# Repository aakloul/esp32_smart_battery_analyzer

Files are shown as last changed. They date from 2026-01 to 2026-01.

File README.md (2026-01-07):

## esp32_smart_battery_analyzer

This device is designed for testing Lithium Battery. It is powered by ESP32 chip that controls four mode of operation: 

1. Charge Mode, 
2. Discharge Mode, 
3. Analyze Mode, 
4. IR Test Mode

This repository is fully featured with schematics (gerber files), bill of materials, stl for 3-D printing, source code for live UI, plotting and retention of battery profiles.

The source code can manage a fleet of those devices analyzing batteries in parallel

### Bluetooth fleet of Smart‑Charger and Battery‑Profile Analyzer

A lightweight, asyncio‑driven Python application that:

- Scans BLE (Eddystone‑TLM) advertisements from ESP32‑based Smart‑Chargers.
- Stores telemetry in a local SQLite database.
- Shows live, curses‑based tables on the terminal.
- Provides a set of scripts to plot historic charge/discharge curves.
- The project follows a tiny MVC pattern (Model ↔ View ↔ Controller) and is deliberately kept dependency‑free apart from Bleak (the BLE stack).

### 🎯 Features at a glance

| Feature	| Description |
| -	| - |
| **BLE scanner** | asynchronous, runs on any Linux host (Pi, laptop, VM).	|
| **Curses UI** | pure‑ASCII, works on head‑less devices.	|
| **SQLite persistence** | simple DAO layer, easy to export data.	|
| **Live plotting** | Matplotlib scripts for single‑ or multi‑battery views.	|
| **Modular architecture** | scanner, repository, UI, and utilities are isolated.	|
| **Extensible** | add new telemetry fields or UI panels with minimum touching of the DB layer.	|

### 📂 Repository layout

```
esp32_smart_battery_analyzer/
│
├─ datasheet_schematics/   # PDFs of schematics & datasheets
├─ gerber/                 # Gerber files for PCB production
├─ stl/                    # 3D‑printable housing & button models
├─ bom/                    # Bill‑of‑Materials (components, parts number)
└─ sources/                # Python source code
   │
   ├─ main.py                  # Bootstrap / async event‑loop starter
   ├─ app_logger.py            # Centralised logging helper
   ├─ controller.py            # MVC controller (model ↔ view glue)
   ├─ curses_view.py           # Curses‑based UI implementation
   ├─ eddystone_scanner.py     # BLE scanner → controller callback
   ├─ hex_helper.py            # HMAC, hex utilities & byte helpers
   ├─ models.py                # Dataclasses: Device, Battery, Telemetry
   ├─ telemetry_db.py          # Low‑level SQLite wrapper (DAO)
   ├─ telemetry_repository.py  # Repository façade (business‑logic service)
   ├─ archive_sqlite.py        # Merge many DBs into a master.db
   ├─ timing_decorator.py      # Simple profiling decorator
   │
   ├─ telemetry_live_plot.py   # Plot a single battery profile live
   ├─ multi_live_plot.py       # Plot several profiles side‑by‑side live
   ├─ overlay_battery_plot.py  # Overlay multiple profiles on one chart
   ├─ ... (other helper scripts)
   └─ Smart_Multipurpose_Battery_Tester
       │
       └─ Smart_Multipurpose_Battery_Tester.ino     # ESP32 sketch (e.g arduino)
```

## 🚀 Getting started

### Prerequisites

- Python ≥ 3.8
- pip (pyenv or a virtual‑env manager of your choice is recommended)
- A Linux host with BLE support (Raspberry Pi, Ubuntu, Debian, …)

### Installation

```bash
# 1️⃣ Clone the repo
git clone https://github.com/aakloul/esp32_smart_battery_analyzer.git
cd esp32_smart_battery_analyzer

# 2️⃣ (Optional) create a virtual environment
python -m venv .venv
source .venv/bin/activate   # on Windows: .venv\Scripts\activate

# 3️⃣ Install dependencies
pip install -r requirements.txt

# 4️⃣ Run the application
python sources/main.py
```

### Plotting utilities

```python
# Plot a set of historic profiles (master.db must exist)
python sources/overlay_battery_plot.py --db ~/battery_profiles/master.db --batteries 2 3 4 5 6

# Live plot of a single battery while the charger runs
python sources/telemetry_live_plot.py

# Compare several batteries side‑by‑side in real time
python sources/multi_live_plot.py``
```

### 🏗️ Architecture Overview

#### Layered responsibilities

| Layer	| Responsibility	| Example class |
| - | - | - |
| Presentation / Runtime |	Starts the async loop, hands callbacks to Bleak	| main.py |
| Domain / Business Logic |	Decodes BLE packets, decides what to store	| EddystoneScanner |
| Application Service	| Coordinates persistence, hides DB details	| TelemetryRepository |
| Infrastructure / Persistence |	Raw SQLite commands, schema creation	| TelemetryDB |
| Utility	| Hex formatting & HMAC verification	| HexHelper |

#### Mermaid class diagram

```mermaid
classDiagram
    %% Core data structures
    class Device {
        +str mac
        +str name
    }
    class Battery {
        +float capacity_mAh
        +float voltage_V
    }
    class Telemetry {
        +datetime timestamp
        +float voltage
        +float current
        +float temperature
    }

    %% Repositories / DAOs
    class TelemetryDB {
        +connect()
        +execute(sql, params)
        +close()
    }
    class TelemetryRepository {
        +save_telemetry(Telemetry)
        +get_by_device(mac)
    }

    %% Scanner & Controller
    class EddystoneScanner {
        +start_scan(callback)
        +stop_scan()
    }
    class Controller {
        +on_packet(packet)
        +update_model()
    }

    %% UI
    class CursesView {
        +draw_header()
        +draw_row(Device)
        +refresh()
    }

    %% Utilities
    class HexHelper {
        +bytes_to_hex(bytes)
        +calc_hmac(key, data)
    }

    %% Relationships
    Device "1" <-- "0..*" Battery : records
    Battery "1" <-- "0..*" Telemetry : records
    TelemetryRepository --> TelemetryDB : uses
    TelemetryDB --> Telemetry : uses
    Controller --> TelemetryRepository : persists
    Controller --> CursesView : updates UI
    CursesView --> Controller : user actions
    EddystoneScanner --> Controller : callback
    EddystoneScanner  ..> HexHelper : validates HMAC
```
The diagram shows the main data classes (Device, Battery, Telemetry) and how the scanner, controller, repository, DB wrapper and UI interact.

#### Principles

The codebase **testable, maintainable, and future‑proof with clear separation**: 
- The scanner never touches SQL; 
- the repository never knows about BLE.
- The UI lives in its own module and the whole application follows a very lightweight MVC pattern (Model = dataclasses + SQLite, View = curses based terminal table, Controller = glue that updates the model and tells the view to redraw).

**Lightweight**: All modules import only the Python standard library plus bleak (already required for BLE). No extra third‑party UI frameworks are needed, keeping the package lightweight and easy to install.

**Requires minimum hardware specifications**, all the UI is ASCII based to allow the capture to run on a headless device (e.g raspberry pi)

**Responsiveness** of the UI and scanning with asyncio and threading

## 🛠️ Development & Contribution

1. Code style – run black . and flake8 before committing.

2. Testing – add unit tests under a tests/ directory (pytest recommended).

3. Profiling UI loops – use the built‑in cProfile wrapper:

```python -m cProfile -o profile.pstats main.py```

After you quit the program, inspect the hot spots:

```python
python - <<'PY'
import pstats, sys
p = pstats.Stats('profile.pstats')
p.strip_dirs().sort_stats('cumtime').print_stats(20)
PY
```
Look for functions that consume a lot of cumulative time (_draw_table, _draw_log, parse_advertisement, etc.). Those are the places to optimise.

4. Pull requests – fork the repo, push your branch, and open a PR. Include a short description of the change and reference any related issue.

## References: 

| Link | |
| - | - |
| [Instructables](https://www.instructables.com/DIY-Smart-Multipurpose-Battery-Tester/) | detailed instructions and schematics |
| [Youtube](https://youtu.be/QN8AuUfg2y8?si=btL3awTXZG-g8NH7) | |
| [PCBWay](https://www.pcbway.com/project/shareproject/DIY_Smart_Multipurpose_Battery_Tester_aaf0922e.html) | PCB production |
| [Seed Studio](https://wiki.seeedstudio.com/XIAO_ESP32C3_Getting_Started/) | Getting Started with ESP32-C3 |
| [Nimble on ESP32-C](https://wiki.seeedstudio.com/XIAO_ESP32C3_Bluetooth_Usage/) | Bluetooth with ESP32-C3 |
| [Nimble-Arduino](https://github.com/h2zero/NimBLE-Arduino/blob/master/examples/BLE_EddystoneTLM_Beacon/BLE_EddystoneTLM_Beacon.ino) | Nimble Eddystone-TLM Beacons |
| [HMAC](https://www.dfrobot.com/blog-921.html?srsltid=AfmBOootriPzmv8BGEABjtGPIYKFY8ldHPTuY8WLx7NJhZGtg5EIOsAH) | HMAC implementation for esp32 chip |

## 📄 License
The code is released under the GPLv3 License – see the LICENSE file for details.

## 🙋‍♀️ Need help?

- Open an issue on GitHub.
- Join the discussion in the Discussions tab for design ideas.
- For quick questions, drop a comment on the relevant PR or issue.

Happy hacking! 🚀

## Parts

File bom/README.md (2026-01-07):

Updated BOM Note – Part Replacement

## Summary

The circuit does not need a MOSFET because the op‑amp supplies a constant low‑voltage current. Replacing the discontinued IRL540 with a simple bipolar transistor works fine – the 2SD972 has been tested successfully

## ⚠️ Important Warnings

| Issue |	Recommendation |
| - |	- |
| IRL540 discontinued	| Do not try to source it; it’s no longer manufactured. |
| PCBWay’s suggested substitute – IRFZ44NPBF	| DO NOT USE. In a low‑voltage gate‑drive configuration the IRFZ44N will not turn on properly, resulting in little or no current flow. |

## Recommended Replacement Options

| Part	|	Type	|	Why it fits	|
| -	|	-	|	- |
| 2SD972	|	NPN bipolar transistor |	Proven to work in this design; handles the required current with the op‑amp’s low‑voltage output. |
|IRLZ44N (logic‑level MOSFET)	|	MOSFET	|	Suitable when you do need a MOSFET driven directly from 3.3 V/5 V microcontrollers (e.g., Arduino, ESP32). It turns fully on at low gate voltages, unlike the standard IRFZ44N which requires ~10 V. |

- Tip: If you ever need a MOSFET for a higher‑voltage gate‑drive application, choose a true logic‑level device (e.g., IRLZ44N) rather than a standard‑level part.
- Tip: For direct use with 3.3V/5V microcontrollers (like Arduino), the IRLZ44N (logic-level) is a better, more efficient choice than the standard IRFZ44N. The primary difference is that the IRLZ44N is a logic-level MOSFET, meaning it can be fully controlled by low-voltage logic (like a 3.3V or 5V microcontroller I/O pin, e.g esp32 chip), while the IRFZ44N is a standard-level MOSFET that requires a higher gate voltage (typically 10V) for full turn-on. 

## Further Reading

Reddit discussion – a community‑curated list of additional MOSFET/ transistor alternatives (link here [Reddit post](https://www.reddit.com/r/AskElectronics/comments/q2pisu/irl_vs_irf_mosfet_can_i_use_an_irf_mosfet_for/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,thus%20standard%2Dlevel.) for more alternatives. )

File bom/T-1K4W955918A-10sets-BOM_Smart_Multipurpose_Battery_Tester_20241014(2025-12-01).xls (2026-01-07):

PCBWay Bom Quotation, Product No.:T-1K4W955918A
Item # | *Designator | *Qty | Manufacturer | *Mfg Part # | Description / Value | Vendor Part # | *Package/Footprint | Your Instructions / Notes | *Unit Price(10 sets) | *Total | *Delivery Time | *Actual Purchase Mfg Part # | *PCBWay Note | Customer Reply | PCBWay Update
1 | D1,D2 | 2 | MDD | SS34 | SS34 | LCSC『 』C8678 | DO-214AC_L4.3-W2.7-LS5.3-RD |  | $0.078 | $1.560
2 | C12,C9,C10,C11,C6,C7,C8,C3 | 8 |  | 0805B104J250CT | 100nF | LCSC『 』C396717 | C0805 |  | $0.018 | $1.440
3 | C1,C2,C4,C5 | 4 |  | CL21A106KPFNNNE | 10uF | LCSC『 』C17024 | C0805 |  | $0.021 | $0.840
4 | R18,R19,R20 | 3 |  | 0805W8F1002T5E | 4.7kΩ | LCSC『 』C17414 | R0805 |  | $0.004 | $0.120 |  | 0805W8F4701T5E
5 | U4 | 1 |  | SKU 113991054 | XIAO ESP32C3 | Seeedstudio | XIAO-ESP32C3-MODULE |  | $8.578 | $85.780 | 7-10 Workdays | 113991054
6 | BZ | 1 |  | GMD0955YB-3V2700 | 2700Hz | LCSC『 』C252933 | BUZ-TH_BD9.0-P5.00-D0.6-FD |  | $0.498 | $4.980
7 | MOD,UP, DOWN | 3 |  | Switch6*6*11 | MOD,UP, DOWN | LCSC『 』C91998 | SW-SMD_4P-L6.0-W6.0-P4.50-LS8.5 | https://item.szlcsc.com/2997628.html?fromZone=s_s__%2522TS-1095PS-A8B3-C3D2%2522 | $0.052 | $1.560 |  | TS-1095PS-A8B3-C3D2
8 | BAT | 1 |  | PH-2P卧贴 | PH2.0-2PWB | LCSC『 』C47647 | CONN-SMD_2P-P2.00_PH2.0-SPWB |  | $0.084 | $0.840
9 | BT | 1 |  | BH-18650-B1BA002 | BH-18650 | LCSC『 』C2988620 | BATTERY-SMD_18650-1S-L77.1-W20.7-1 |  | $1.563 | $15.630 |  |  | 【 Sensitive Components 】 : Before mounting, dehumidification and baking are required. Bake at 60-70 degrees for 10-25 minutes
10 | DSP | 1 |  | HS96L03W2C03 | OLED 0.96 INCH 128X64 I2C | LCSC『 』C5248080 | OLED 0.96 INCH 128X64 I2C |  | $2.341 | $23.410
11 | LED | 1 |  | 17-21SURC/S530-A3/TR8 | LED-0805_R | C72037 | LED0805_RED |  | $0.033 | $0.330
12 | Q3 | 1 |  | 2SD972 | IRL540 discontuned --> replace with iscSilicon NPN Darlington Power Transistor (https://www.alldatasheet.com/datasheet-pdf/view/895356/ISC/2SD972.html) | LCSC『 』C2586 | TO-220-3_L10.0-W4.5-P2.54-L |  | $0.250 | $2.500 |  |  |  | IRFZ44NPBF won't work because it's gate threshold is too high (around 10V) and therefore we need another TO-220 FET that can be activated around 4V
13 | R1,R2,R6 | 3 |  | RMC08051K5%N | 5.1kΩ | LCSC『 』C269727 | R0805 |  | $0.005 | $0.150 |  | 0805W8F5101T5E
14 | R3,R4,R13,R7,R9 | 5 |  | RMC08051K5%N | 1kΩ | LCSC『 』C269727 | R0805 |  | $0.005 | $0.250
15 | R5 | 1 |  | RMC08051K5%N | 10kΩ | LCSC『 』C269727 | R0805 |  | $0.007 | $0.070 |  | 0805W8F1002T5E
16 | R11 | 1 |  | PTFR0805B33K0N9 | 33kΩ | LCSC『 』C351577 | R0805 |  | $0.561 | $5.610
17 | R12,R14 | 2 |  | 0805W8F1002T5E | 10kΩ | LCSC『 』C17414 | R0805 |  | $0.005 | $0.100
18 | R16 | 1 |  | RC0805JR-07200KL | 200K | LCSC『 』C114235 | R0805 |  | $0.007 | $0.070
19 | R17 | 1 |  | RMC0805100K5%N | 100kΩ | LCSC『 』C269722 | R0805 |  | $0.016 | $0.160
20 | R8 | 1 |  | RS-05K2001FT | 2k | LCSC『 』C132365 | R0805 |  | $0.008 | $0.080
21 | R15 | 1 |  | 25121WF100LT4E | 100mΩ/1W | LCSC『 』C25466 | R2512 |  | $0.142 | $1.420
22 | USB_5V | 1 |  | TYPE-C 6P | TYPE-C 6P | LCSC『 』C456012 | TYPE-C-SMD_TYPE-C-6P |  | $0.049 | $0.490
23 | HS | 1 |  | 23.5*16*25 | 23.5*16*25 | LCSC『 』C4661 | HEATSINK-TH_L23.5-W16.0-P18.0_XSD2156-067 | 若原型号型号，可以购买https://item.taobao.com/item.htm?id=787746231050&spm=a21m98.27004841『 』用右边这个链接『 』https://item.taobao.com/item.htm?id=904397829229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 | $0.223 | $2.230 |  | Two nail heat sinks of 23.5*16*25
24 | Q1 | 1 |  | AO3401A | AO3401A | LCSC『 』C5122001 | SOT-23-3_L2.9-W1.3-P1.90-LS2.4-BR |  | $0.087 | $0.870
25 | Q2 | 1 |  | 2SC2411KT146R | 2SC2411 | LCSC『 』C122622 | SOT-346_L2.9-W1.6-P1.90-LS2.8-TR-CW |  | $0.073 | $0.730
26 | U1 | 1 |  | LP4060B5F | LP4060 | LCSC『 』C517259 | TSOT-23-5_L2.9-W1.6-P0.95-LS2.8-BR |  | $0.073 | $0.730
27 | U2 | 1 |  | AP6685 | AP6685 | LCSC『 』C2849566 | SOT-23-5_L2.9-W1.6-P0.95-LS2.8-BL |  | $0.103 | $1.030
28 | U3 | 1 | HXY MOSFET(华轩阳电子) | XC6206P332MR | XC6206P332MR | LCSC『 』C5148692 | SOT-23-3_L2.9-W1.3-P1.90-LS2.4-BR |  | $0.099 | $0.990
29 | U5 | 1 |  | LMV321B-TR | LMV321B-TR | LCSC『 』C248567 | SOT-23-5_L3.0-W1.7-P0.95-LS2.8-BR |  | $0.204 | $2.040
30 | U6 | 1 |  | LM385-1.2 | LM385-1.2 | LCSC『 』C5274784 | SOT-23-3_L2.9-W1.4-P1.90-LS2.5-BR |  | $0.388 | $3.880
31 | PWR | 1 |  | SK-12E12-G050 | SK-12E12-G050 | LCSC『 』C2848870 | SW-TH_G-SWITCH_SK-12E12-G050 |  | $0.118 | $1.180
32 | / | 1 | XFCN | PZ254V-11-04P | 1x4 male header, used for DSP |  |  |  | $0.044 | $0.440
33 | / | 1 |  |  | Insulation sheet and insulation cap for HS |  |  | https://item.taobao.com/item.htm?abbucket=2&id=621632934312&ns=1&spm=a21n57.1.0.0.13a2523cTEn6rm | $0.150 | $1.500 |  | Insulating sheet + insulating cap
34 | / | 1 |  |  | M3 screw for HS |  |  | https://item.taobao.com/item.htm?abbucket=2&id=621632934312&ns=1&spm=a21n57.1.0.0.13a2523cTEn6rm | $0.076 | $0.760 |  | M3*6(length 6mm) screws
 |  |  |  |  |  |  |  |  | Component Cost | $163.77
 |  |  |  |  |  |  |  |  | Assembly Cost | $29.00
 |  |  |  |  |  |  |  |  | PCB Cost | $5.00
 |  |  |  |  |  |  |  |  | All Total 10 Sets | $197.77

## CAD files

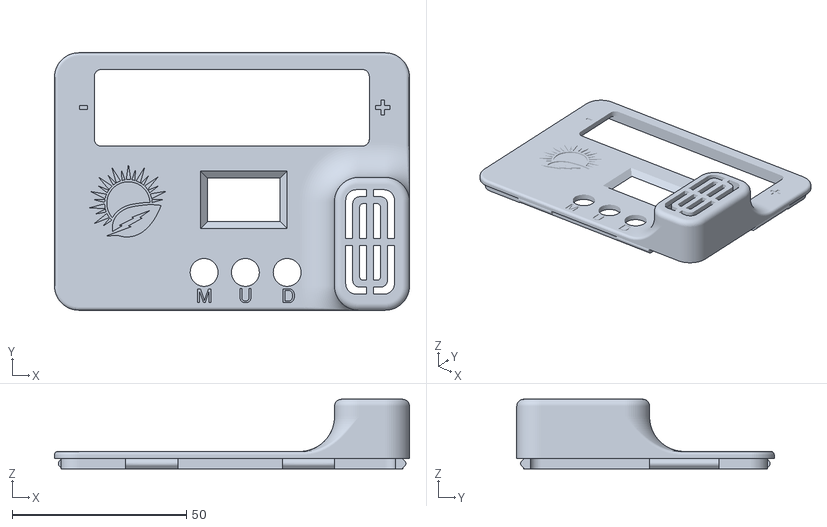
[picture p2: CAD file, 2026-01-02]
stl/Cover_PCBWay Community.stl
102.0 x 74.0 x 20.0

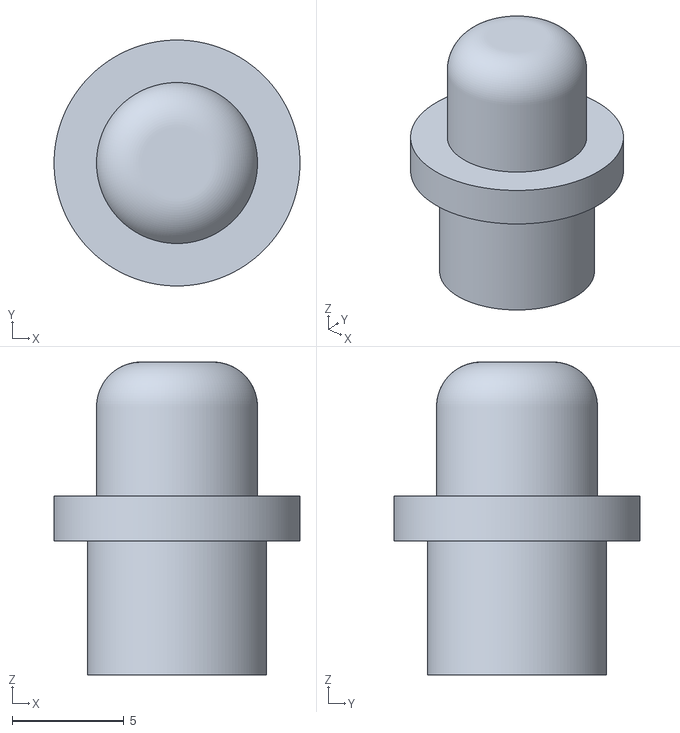
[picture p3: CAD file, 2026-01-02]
stl/Buttons_PCBWay Community.stl
11.0 x 11.0 x 14.0

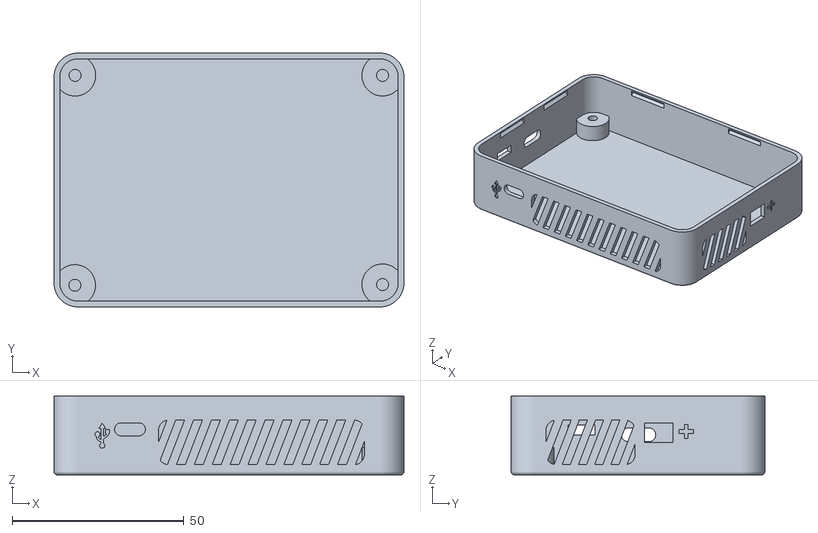
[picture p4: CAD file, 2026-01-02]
stl/Housing_PCBWay Community.stl
102.0 x 74.0 x 23.0

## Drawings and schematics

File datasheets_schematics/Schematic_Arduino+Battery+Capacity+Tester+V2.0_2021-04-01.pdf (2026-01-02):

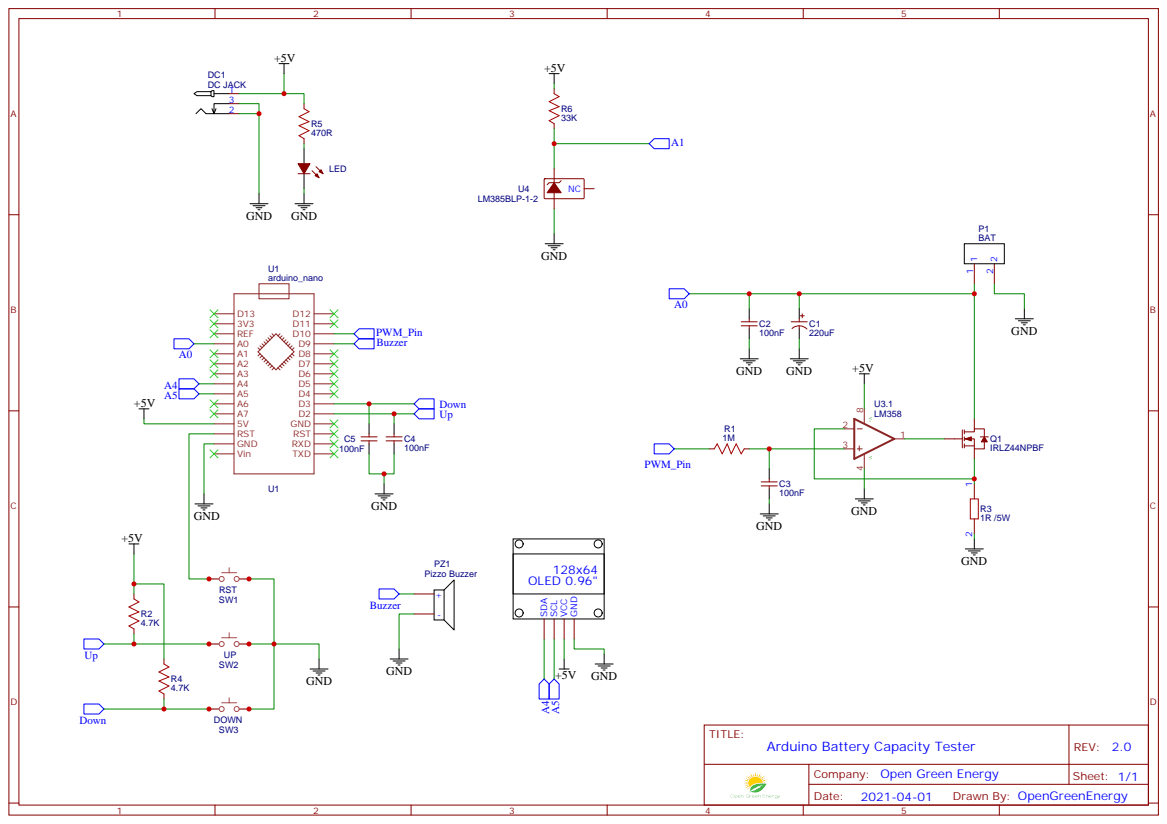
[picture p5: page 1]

Company: Open Green Energy

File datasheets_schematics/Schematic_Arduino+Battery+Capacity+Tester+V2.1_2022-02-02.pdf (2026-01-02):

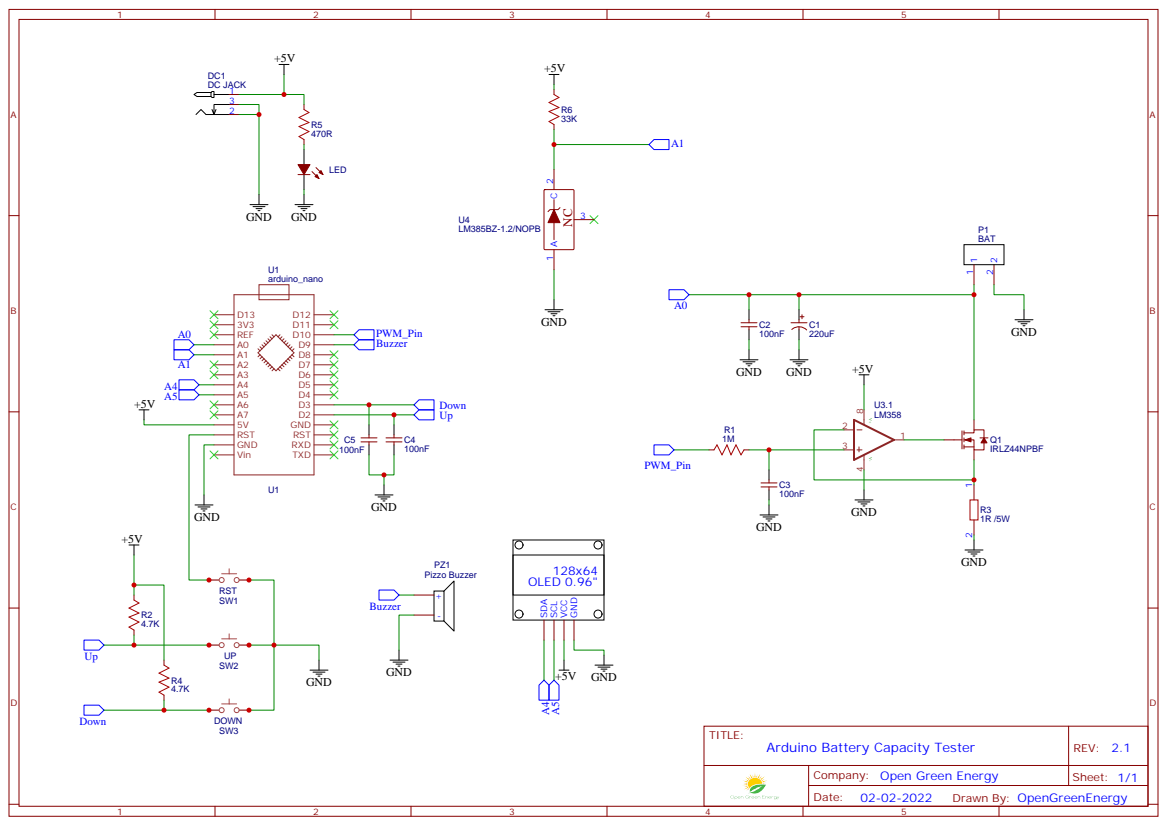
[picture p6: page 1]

Company: Open Green Energy

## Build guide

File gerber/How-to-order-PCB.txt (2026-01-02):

How to Order PCB

Please refer to:
https://docs.easyeda.com/en/PCB/Order-PCB

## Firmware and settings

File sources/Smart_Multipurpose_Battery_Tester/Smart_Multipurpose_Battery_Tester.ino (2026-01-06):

//>>>>>>>>>>>>>>>>>>>>>>>>>>>>>>>>>>>>>>>>>>>>>>>>>>>>>
// DIY Smart Multipurpose Battery Tester
// by Open Green Energy, INDIA ( www.opengreenenergy.com )
// Beta Version 
// Last Updated on: 25.10.2024
//>>>>>>>>>>>>>>>>>>>>>>>>>>>>>>>>>>>>>>>>>>>>>>>>>>>>>

#include <Wire.h>
#include <Adafruit_GFX.h>
#include <Adafruit_SSD1306.h>
#include <JC_Button.h>

//>>>>>>>>>>>>>>>>>>>>>>>>>>>>>>>>>>>>>>>>>>>>>>>>>>>>>
// Bluetooth support
//>>>>>>>>>>>>>>>>>>>>>>>>>>>>>>>>>>>>>>>>>>>>>>>>>>>>>
#include <Arduino.h>
#include <NimBLEDevice.h>
#include <NimBLEEddystoneTLM.h>
#include <sys/time.h>
#include <esp_sleep.h>
#include <mbedtls/md.h>          // mbedTLS is bundled with the ESP32 Arduino core


#define GPIO_DEEP_SLEEP_DURATION 10 // sleep x seconds and then wake up
#define BEACON_POWER             3  // 3dbm

# define ENDIAN_CHANGE_U16(x) ((((x) & 0xFF00) >> 8) + (((x) & 0xFF) << 8))
# define ENDIAN_CHANGE_U32(x) \
     ((((x) & 0xFF000000) >> 24) + (((x) & 0x00FF0000) >> 8)) + ((((x) & 0xFF00) << 8) + (((x) & 0xFF) << 24))

RTC_DATA_ATTR static time_t   last;      // remember last boot in RTC Memory
RTC_DATA_ATTR static uint32_t bootcount; // remember number of boots in RTC Memory
NimBLEAdvertising*            pAdvertising;
struct timeval                nowTimeStruct;

//#define BEACON_UUID \
//    "8ec76ea3-6668-48da-9866-75be8bc86f4d" // UUID 1 128-Bit (may use linux tool uuidgen or random numbers via https://www.uuidgenerator.net/)

unsigned int count = 1; //Number of messages sent
unsigned long lastAdvertisedVoltage = 0;  // Last voltage advertised in BLE beacon
unsigned long lastAdvertisedTimestamp = 0;  // Last voltage advertised in BLE beacon

char *HMAC_KEY = "secretKey";  // <-- replace with your own secret                      

static const uint8_t MAC_TRUNC_LEN = 4;   // bytes of HMAC to keep (4‑8 is typical)
static const uint16_t ADV_INTERVAL_MS = 1000;
static const uint8_t   EDDYSTONE_UUID[] = {0xAA, 0xFE}; // 0xFEAA (Eddystone)

static uint32_t advCount = 0;   // number of advertisements sent

// ------------------------------------------------------------
// Voltage‑stagnation detector (used in chargeMode)
// ------------------------------------------------------------
float   lastSeenVoltage      = 0.0;                     // voltage the last time we saw a rise
unsigned long lastRiseMillis = 0;                       // millis() when that rise happened
const unsigned long STAGNATION_TIMEOUT = 10UL * 60UL * 1000UL; // 10 min in ms
const float MIN_RISE_V       = 5;                             // 5 mV = 0.005 V
bool    stagnationDetected   = false;                    // flag to can act on
bool    voltageDropDetected  = false;                    // flag to can act on
                                              
//>>>>>>>>>>>>>>>>>>>>>>>>>>>>>>>>>>>>>>>>>>>>>>>>>>>>>
// DIY Smart Charger
//>>>>>>>>>>>>>>>>>>>>>>>>>>>>>>>>>>>>>>>>>>>>>>>>>>>>>

// Define OLED display dimensions and reset pin
#define SCREEN_WIDTH 128
#define SCREEN_HEIGHT 64
#define OLED_RESET -1

// Create an instance of the SSD1306 display object
Adafruit_SSD1306 display(SCREEN_WIDTH, SCREEN_HEIGHT, &Wire, OLED_RESET);

// Define GPIO pins for buttons
#define MODE_PIN D3
#define UP_PIN D6
#define DOWN_PIN D9

// Instantiate Button objects
Button Mode_Button(MODE_PIN, 15, false, true);  // GPIO 3 on XIAO ESP32C3 (D3)
Button UP_Button(UP_PIN, 15, false, true);      // GPIO 6 on XIAO ESP32C3 (D6)
Button Down_Button(DOWN_PIN, 15, false, true);  // GPIO 9 on XIAO ESP32C3 (D9)
unsigned long upLastChange = 0;
unsigned long downLastChange = 0;
unsigned long modeLastChange = 0;

// Mode selection variables
int selectedMode = 0;
bool modeSelected = false;
bool inAnalyzeMode = false;  // To track if analyze mode is running

float cutoffVoltage = 3.0;        // Default cutoff voltage, to be selected by user
const float Min_BAT_level = 2.8;  // Minimum threshold voltage for discharge
const float Max_BAT_level = 3.2;  // Maximum threshold voltage for discharge
const float FULL_BAT_level = 4.18;  // Threshold voltage for stopping charge ( Typical Value is 4.2V )
const float DAMAGE_BAT_level = 2.5;  // Define voltage for damged battery
const float NO_BAT_level = 0.3;  // Define voltage for empty slot 

int Current[] = {0, 50, 100, 200, 300, 400, 500, 600, 700, 800, 900, 1000};
int PWM[] = {0, 4, 10, 20, 30, 40, 50, 60, 70, 80, 90, 100};
int Array_Size = sizeof(Current) / sizeof(Current[0]);
//int Current_Value = 0;
int currentOffset = 25; // Default offset current
int PWM_Value = 0;
int PWM_Index = 0;

unsigned long Capacity = 0;
float Capacity_f = 0;
float Vref_Voltage = 1.227;  // LM385-1.2V reference voltage ( adjust it for calibration )
float Vcc = 3.3;
float BAT_Voltage = 0;
float InternalResistance = 0;
float sample = 0;
bool calc = false, Done = false, Report_Info = true;

// Define global time variables
unsigned long previousMillis = 0;
const long interval = 50;  // Interval to update the battery icon
unsigned long startTime = 0;  // Store the start time for the entire process
unsigned long elapsedTime = 0;  // Total elapsed time

// Declare Hour, Minute, and Second globally
int Hour = 0;
int Minute = 0;
int Second = 0;

// Control pins
const byte PWM_Pin = D8;    // GPIO 8 on XIAO ESP32C3 (D8)
const byte Buzzer = D7;     // GPIO 7 on XIAO ESP32C3 (D7)
const int BAT_Pin = A0;     // GPIO 0 on XIAO ESP32C3 (A0)
const int Vref_Pin = A1;    // GPIO 1 on XIAO ESP32C3 (A1)
const byte Mosfet_Pin = D2; // GPIO 2 on XIAO ESP32C3 (D2)

// Battery level for icon
int batteryLevel = 0;

// Resistor values for the voltage divider
const float R1 = 200000.0;  // 200k ohms
const float R2 = 100000.0;  // 100k ohms

// ========================================= SETUP FUNCTION ========================================
void setup() {
    Serial.begin(115200);

    NimBLEDevice::init("TLMBeacon");
    NimBLEDevice::setPower(BEACON_POWER);

    // Get the device's address
    NimBLEAddress myAddress = NimBLEDevice::getAddress();
    Serial.printf("BLE MAC Address: %s\n", myAddress.toString().c_str());

    pAdvertising = NimBLEDevice::getAdvertising();

    // We'll rebuild the whole Service Data each iteration
    // because the MAC depends on the payload.
    pAdvertising->setConnectableMode(BLE_GAP_CONN_MODE_NON);
    uint16_t minInterval = ADV_INTERVAL_MS / 0.625; 
    uint16_t maxInterval = ADV_INTERVAL_MS / 0.625; // Set min and max to the same value for a fixed interval

    pAdvertising->setMinInterval(minInterval);
    pAdvertising->setMaxInterval(maxInterval);
    

    pinMode(PWM_Pin, OUTPUT);
    pinMode(Buzzer, OUTPUT);
    pinMode(Mosfet_Pin, OUTPUT);
    analogWrite(PWM_Pin, PWM_Value);
    UP_Button.begin();
    Down_Button.begin();
    Mode_Button.begin();

    // Initialize the OLED display with I2C address 0x3C
    if (!display.begin(SSD1306_SWITCHCAPVCC, 0x3C)) {
        for (;;); // Stop if OLED initialization fails
    }

    // Clear the buffer
    display.clearDisplay();
    display.setTextColor(SSD1306_WHITE);
    // Display the Logo during startup 
    display.setTextSize(1);
    display.setCursor(25, 12);
    display.print("Lantau Hackers");
    display.setCursor(25, 40);
    display.print(myAddress.toString().c_str());
    display.display();
    delay(2000);

    // Start mode selection
    selectMode();

}



// ========================================= LOOP FUNCTION ========================================
void loop() {
    if (modeSelected) {
        if (selectedMode == 0) {
            chargeMode();
        } else if (selectedMode == 1) {
            dischargeMode();
        } else if (selectedMode == 2) {
            analyzeMode();
        } else if (selectedMode == 3) {
            internalResistanceMode();   // IR test mode added
            delay(5000);                // Wait for the user to read the display
        }
        selectMode();  // Return to mode selection after task is completed
    }
}

// ========================================= MODE SELECTION ========================================
void selectMode() {
    modeSelected = false;
    selectedMode = 0;

    while (!modeSelected) {
        Mode_Button.read();
        UP_Button.read();
        Down_Button.read();

        // Handle UP button press (move up in the menu)
        if (UP_Button.isPressed() && UP_Button.lastChange() != upLastChange) {
            selectedMode = (selectedMode == 0) ? 3 : selectedMode - 1;  // If at the top, wrap around to the bottom
            beep(100);
            delay(100);  // Debounce delay to prevent multiple presses
        }

        // Handle DOWN button press (move down in the menu)
        if (Down_Button.isPressed() && Down_Button.lastChange() != downLastChange) {
            selectedMode = (selectedMode == 3) ? 0 : selectedMode + 1;  // If at the bottom, wrap around to the top
            beep(100);
            delay(100);  // Debounce delay to prevent multiple presses
        }

        // Confirm selection with MODE button press
        if (Mode_Button.isPressed() && Mode_Button.lastChange() != modeLastChange) {
            beep(300);
            modeSelected = true;
            delay(100);  // Debounce delay to prevent multiple presses
        }

        upLastChange = UP_Button.lastChange();
        downLastChange = Down_Button.lastChange();
        modeLastChange = Mode_Button.lastChange();

        // Display the menu options and highlight the selected one
        display.clearDisplay();
        display.setTextSize(1);
        display.setCursor(25, 0);
        display.print("Select Mode:");
        display.setCursor(25, 12);
        display.print((selectedMode == 0) ? "> Charge" : "  Charge");
        display.setCursor(25, 26);
        display.print((selectedMode == 1) ? "> Discharge" : "  Discharge");
        display.setCursor(25, 40);
        display.print((selectedMode == 2) ? "> Analyze" : "  Analyze");
        display.setCursor(25, 54);
        display.print((selectedMode == 3) ? "> IR Test" : "  IR Test");
        display.display();
    }

    // Show the selected mode after selection
    display.clearDisplay();
    display.setTextSize(2);
    display.setCursor(10, 20);
    if (selectedMode == 0) {
        display.print("Charge..");
    } else if (selectedMode == 1) {
        display.print("Dischrg..");
    } else if (selectedMode == 2) {
        display.print("Analyze..");
    } else if (selectedMode == 3) {
        display.print("IR Test..");
    }
    display.display();
    delay(500);
}

// ========================================= MEASURE BATTERY VOLTAGE ========================================
float measureVcc() {
    float vrefSum = 0;  // Sum of all the Vref readings
    for (int i = 0; i < 100; i++) {
        vrefSum += analogRead(Vref_Pin);  // Read raw analog value from Vref pin 100 times
        delay(2);  // Small delay between each reading for stability
    }
    float averageVrefReading = vrefSum / 100.0;  // Calculate the average Vref reading
    float vcc = (Vref_Voltage * 4096.0) / averageVrefReading;  // Calculate Vcc using average Vref and 12-bit ADC
    return vcc;
}

float measureBatteryVoltage() {
    Vcc = measureVcc();  // Measure the actual Vcc
    float batterySum = 0;  // Sum of all the battery readings
    for (int i = 0; i < 100; i++) {
        batterySum += analogRead(BAT_Pin);  // Read raw analog value from the battery pin 100 times
        delay(2);  // Small delay between each reading for stability
    }
    float averageBatteryReading = batterySum / 100.0;  // Calculate the average battery reading
    float voltageDividerRatio = (R1 + R2) / R2;
    float batteryVoltage = (averageBatteryReading * Vcc / 4096.0) * voltageDividerRatio;      // Convert ADC value to battery voltage
    return batteryVoltage;
}

// ========================================= UPDATE THE ELAPSED TIME =============================
void updateTiming() {
    unsigned long currentMillis = millis();
    elapsedTime = currentMillis - startTime;  // Calculate total elapsed time since the process started

    // Convert elapsed time to hours, minutes, and seconds
    Second = (elapsedTime / 1000) % 60;
    Minute = (elapsedTime / (1000 * 60)) % 60;
    Hour = (elapsedTime / (1000 * 60 * 60));
}

// ========================================= CHARGE MODE ========================================
void chargeMode() {
    calc = true;
    Done = false;
    Capacity = 0;  // Reset capacity for the test
    unsigned long lastUpdateTime = millis();  // Start timer for the charging process
    batteryLevel = 0;  // Start from 0%

    // Measure battery voltage before starting the charge
    BAT_Voltage = measureBatteryVoltage();

    // Check if the battery voltage is below the minimum threshold
    if (BAT_Voltage < NO_BAT_level) {
        // If battery voltage is below NO_BAT_level, display "No Battery"
        display.clearDisplay();
        display.setTextSize(1);
        display.setCursor(15, 25);
        display.print("EMPTY BAT SLOT");
        display.display();
        delay(3000);  // Wait for 3 seconds
        //selectMode();  // Return to mode selection
        return;
    } else if (BAT_Voltage < DAMAGE_BAT_level) {
        // If battery voltage is below DAMAGE_BAT_level but above NO_BAT_level, consider the battery damaged
        display.clearDisplay();
        display.setTextSize(1);
        display.setCursor(25, 25);
        display.print("BAT DAMAGED");
        display.display();
        delay(3000);  // Wait for 3 seconds
        //selectMode();  // Return to mode selection
        return;
    } 

    // If the battery voltage is between Min_BAT_level and FULL_BAT_level, proceed with charging
    digitalWrite(Mosfet_Pin, HIGH);  // Turn on MOSFET to start charging

    // ---- reset stagnation detector for this session ----
    lastSeenVoltage     = BAT_Voltage;         // current voltage is our baseline
    lastRiseMillis      = millis();            // start the timer
    stagnationDetected  = false;
    voltageDropDetected = false;

    while (!Done) {
        updateTiming();
        BAT_Voltage = measureBatteryVoltage();  // Measure battery voltage    

        // ------------------------------------------------------------
        //  Stagnation detection
        // ------------------------------------------------------------
        if (BAT_Voltage - lastSeenVoltage > MIN_RISE_V) {
            // We saw a meaningful rise – move the “last good” marker forward
            lastSeenVoltage = BAT_Voltage;
            lastRiseMillis   = millis();
        } else if (millis() - lastRiseMillis >= STAGNATION_TIMEOUT) {
            // No rise of ≥0.1 mV for 10 min → flag it
            stagnationDetected = true;
            if (BAT_Voltage - lastSeenVoltage < 0) {
                voltageDropDetected = true;
            }
        }

        // react immediately here, e.g. stop charging: 
        //e.g send a beacon or increase charging voltage in a controlled manner
        if (stagnationDetected) { /* … */ 
            Done = true;
            digitalWrite(Mosfet_Pin, LOW);  // Turn off MOSFET to stop charging
        } else {
            display.clearDisplay();
            // Simulate battery charging progression
            updateBatteryDisplay(true);  // True indicates charging
            display.setTextSize(1);
            display.setCursor(25, 5);
            display.print("Charging ");
            display.print(Current[PWM_Index]);
            display.print("mA");
            display.setCursor(40, 25);
            if(Hour < 10) display.print(0);
            display.print(Hour);
            display.print(":");
            if(Minute < 10) display.print(0);
            display.print(Minute);
            display.print(":");
            if(Second < 10) display.print(0);
            display.print(Second);       
            display.setTextSize(2);
            display.setCursor(15, 40);
            display.print("V:");
            display.print(BAT_Voltage,2);
            display.print("V");
            display.display();

            bool voltage_changed = (lastAdvertisedVoltage != BAT_Voltage);
            bool ten_sec_since_last_beacon = (elapsedTime - lastAdvertisedTimestamp) > 10000;
            if (voltage_changed && ten_sec_since_last_beacon) {
                lastAdvertisedVoltage = BAT_Voltage;
                lastAdvertisedTimestamp = elapsedTime;
                //  advertiseBeacon();
            }
            advertiseBeacon();
        }

        // Check if battery voltage has reached the full battery level
        if (BAT_Voltage >= FULL_BAT_level || stagnationDetected) {
            Done = true;
            digitalWrite(Mosfet_Pin, LOW);  // Turn off MOSFET to stop charging
            beep(300);  // Beep to indicate charging is complete
            displayFinalCapacity(true, stagnationDetected);  // Pass true for charging complete            
        }  
        //  delay(100);      
    }
    //selectMode();  // Return to mode selection after charging is complete
}

// ========================================= DISCHARGE MODE ========================================
void dischargeMode() {
    bool cutoffSelected = selectCutoffVoltage();
    bool currentSelected = selectDischargeCurrent();

    if (cutoffSelected && currentSelected) {
        calc = true;
        Done = false;
        Capacity = 0;  // Reset capacity for the test
        unsigned long lastUpdateTime = millis();  // Start timer for the discharging process

        digitalWrite(Mosfet_Pin, LOW);  // Ensure the charging MOSFET is off
        analogWrite(PWM_Pin, PWM_Value);  // Start discharging by applying PWM to the load

        while (!Done) {
            updateTiming();
            BAT_Voltage = measureBatteryVoltage();  // Measure the battery voltage

            // Calculate time elapsed since the last update
            unsigned long currentTime = millis();
            float elapsedTimeInHours = (currentTime - lastUpdateTime) / 3600000.0;  // Convert ms to hours

            // Update capacity using I * t (Current * elapsed time)
            if (calc) {
                Capacity_f += (Current[PWM_Index] + currentOffset) * elapsedTimeInHours;  // Capacity in mAh
                lastUpdateTime = currentTime;  // Update last update time
            }

            display.clearDisplay();
            updateBatteryDisplay(false);  // Update battery icon (false for discharging)
            display.setTextSize(1);
            display.setCursor(15, 5);
            display.print("Discharging..");
            display.setCursor(15, 20);
            display.print("Time: ");
            if(Hour < 10) display.print(0);
            display.print(Hour);
            display.print(":");
            if(Minute < 10) display.print(0);
            display.print(Minute);
            display.print(":");
            if(Second < 10) display.print(0);
            display.print(Second);
            display.setCursor(15, 35);
            display.print("Cap:");
            display.print(Capacity_f, 1);
            display.print("mAh");
            display.setCursor(15, 50);
            display.print("V: ");
            display.print(BAT_Voltage, 2);
            display.print("V");
            display.display();

            bool voltage_changed = (lastAdvertisedVoltage != BAT_Voltage);
            bool ten_sec_since_last_beacon = (elapsedTime - lastAdvertisedTimestamp) > 10000;
            if (voltage_changed && ten_sec_since_last_beacon) {
                lastAdvertisedVoltage = BAT_Voltage;
                lastAdvertisedTimestamp = elapsedTime;
                //advertiseBeacon();
            }
            advertiseBeacon();

            if (BAT_Voltage <= cutoffVoltage) {
                Done = true;
                analogWrite(PWM_Pin, 0);  // Stop discharging by turning off the load (PWM)
                beep(300);  // Long beep to indicate discharging is complete
                displayFinalCapacity(false, false);  // Pass false for discharging complete
            }
          //  delay(100);
        }
    }
    //selectMode();  // Return to mode selection after discharging is complete
}
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

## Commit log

2026-01-05 plot_battery_profile (#14)
    fix bom
    [T-1K4W955918A-10sets-BOM_Smart_Multipurpose_Battery_Tester_20241014(2025-12-01).xls]
2026-01-06 Log discharge current with telemetry (#16)
    * log_discharge_current_with_telemetry
    * live_plot_telemetry
    * merge_and_archive_multiple_database_of_battery_profiles
    * multi_live_plot_scaled
2026-01-07 Multiple updates on doc decorator bom plots logger (#17)
    * revised_documentation_and_bom
    * timing_decorator
    * shift_all_plots_left_to_align_zero_uptime_with_discharge_starting
    * overlay_multiple_battery_plot_over_the_same_chart_for_easy_comparison
    [T-1K4W955918A-10sets-BOM_Smart_Multipurpose_Battery_Tester_20241014(2025-12-01).xls]
